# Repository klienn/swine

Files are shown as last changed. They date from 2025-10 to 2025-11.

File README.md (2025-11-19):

# SwineTrack – Right on Time, Healthy Swine

SwineTrack is an end-to-end sensing platform for pig pens. A primary ESP32 collects BME680 air-quality data, MLX90640 thermal grids, and pulls RGB frames from an ESP32-CAM. The firmware pushes signed telemetry to Supabase Functions/Storage, exposes a local real-time thermal stream, and drives the same datasets that power the mobile application APIs documented below.

---

## Table of Contents
- [Overview](#overview)
- [Repository Layout](#repository-layout)
- [Hardware Reference](#hardware-reference)
- [Firmware Setup](#firmware-setup)
  - [swine-esp32 (sensor + uploader)](#swine-esp32-sensor--uploader)
  - [swine-esp32-cam (optical module)](#swine-esp32-cam-optical-module)
- [Local Thermal Endpoints](#local-thermal-endpoints)
- [Cloud Pipeline & APIs](#cloud-pipeline--apis)
  - [Edge Upload Endpoints](#edge-upload-endpoints)
    - [GET /config](#get-config)
    - [POST /ingest-live-thermal](#post-ingest-live-thermal)
    - [POST /ingest-live-frame](#post-ingest-live-frame)
    - [POST /ingest-snapshot](#post-ingest-snapshot)
  - [Client/App Data Access](#clientapp-data-access)
    - [1. Live](#1-live)
    - [2. Snapshots (Diary)](#2-snapshots-diary)
    - [3. Readings (History)](#3-readings-history)
    - [4. Alerts](#4-alerts)
- [License](#license)

---

## Overview

The updated deployment uses **two ESP32-class boards on the same Wi-Fi**:

- `swine-esp32` (DevKitC/WROVER class) owns the sensors, hosts a local SSE thermal stream, and uploads multi-part payloads to Supabase Functions using an HMAC signature (`X-Device-Id`, `X-Timestamp`, `X-Signature`).
- `swine-esp32-cam` (AI Thinker-style ESP32-CAM) stays close to the animals and exposes `http://<cam>/capture?...` for RGB frames. The main board polls this endpoint so the heavier neural/video work can happen in the cloud.

On the cloud side the data lands in Storage buckets (`frames-live`, `snapshots`) and Postgres tables (`readings`, `alerts`). The React Native sample code from the old README still applies, so it lives in the **Client/App Data Access** section.

---

## Repository Layout

- `swine-esp32/` – main firmware (`swine-esp32.ino`) plus helpers:
  - `swinetrack_sensors.h` – BME680 + MLX90640 setup, VOC heuristics, JSON builders.
  - `async_http_uploader.h` – background TLS uploader with retry/backpressure.
  - `swinetrack_http.h` – Wi-Fi/time helpers, camera fetch, remote config, TLS CA (`swt_certs.h`).
  - `swinetrack_local_server.h` – lightweight HTTP/SSE server for thermal previews.
  - `esp32_bb.png` / `esp32.fzz` – wiring reference for the sensor shield.
- `swine-esp32-cam/` – ESP32-CAM sketch based on Espressif’s WebServer example (`board_config.h`, `app_httpd.cpp`).
- `README.md` – this document.

---

## Hardware Reference

Minimum bill of materials:

- ESP32 DevKitC / WROVER module with PSRAM (main board).
- ESP32-CAM (AI-Thinker profile by default).
- MLX90640 thermal array (I²C @ 0x33).
- BME680 environmental sensor (I²C @ 0x76/0x77).
- Shared 5 V supply for camera and 3.3 V for the sensors.

`swine-esp32/esp32_bb.png` and `swine-esp32/esp32.fzz` show the exact wiring. Core signals:

| Peripheral | ESP32 Pin | Notes |
|---|---|---|
| I²C SDA | GPIO21 | Shared between BME680 + MLX90640 |
| I²C SCL | GPIO22 | 100 kHz at boot, bumped to 400 kHz after init |
| Camera | Wi-Fi | `CAMERA_URL` must resolve from the main ESP32 |

Keep the two boards on the same SSID. The `swine-esp32` firmware will reboot itself if Wi-Fi or SNTP cannot be re-established.

---

## Firmware Setup

### swine-esp32 (sensor + uploader)

1. **Install libraries**: ESP32 board support ≥ 3.x, `Adafruit BME680`, `Adafruit MLX90640`, `ArduinoJson`, plus the default ESP32 Wi-Fi stack (already bundled).
2. **Edit configuration constants** in `swine-esp32/swine-esp32.ino`:
   - `WIFI_SSID` / `WIFI_PASS` – WPA2 credentials.
   - `FN_BASE` – Supabase Functions base URL (`https://<ref>.functions.supabase.co`).
   - `DEVICE_ID` / `DEVICE_SECRET` – provisioned per device; the secret signs every HTTPS request.
   - `CAMERA_URL` – default `http://cam-pen1.local/capture?res=VGA` but overridden remotely via `/config`.
   - `LIVE_FRAME_INTERVAL_MS`, `READING_INTERVAL_MS`, `REALTIME_THERMAL_INTERVAL_MS`, `FEVER_C`, etc. (all tunable via `/config`).
3. **Verify certificates** inside `swine-esp32/swt_certs.h`. Replace the pin if Supabase rotates their CA chain.
4. **Build & flash** with an “ESP32 Dev Module” (or WROVER) profile and a partition scheme that offers ≥3 MB for the app plus PSRAM.

Behavior highlights:

- Wi-Fi guard + SNTP sync keep the device online; if cloud sync fails it still publishes to the local SSE server.
- The thermal server (port `8787`) publishes events every `REALTIME_THERMAL_INTERVAL_MS` (~50 ms) and survives even when Supabase is unreachable.
- Remote configuration: once time sync succeeds, the device hits `GET /config` for `camera_url`, `live_frame_interval_s`, `reading_interval_s`, `overlay_alpha`, and `fever_c`. Failures just fall back to the compiled defaults.
- `AsyncUploader` batches multi-part POSTs on core 1. It drops stale live frames (>10 s) and prioritizes alerts via `enqueuePriority`.
- Snapshots trigger when `MLX90640` reports `tMax > FEVER_C` or the BME680 gas resistance drops more than `kAirQualityRatioThreshold` (1.5×) from baseline. A five-minute cooldown prevents alert spam.

### swine-esp32-cam (optical module)

- Uses Espressif’s camera HTTP server with the AI-Thinker pinout (`board_config.h`). Enable a different board by uncommenting the relevant macro.
- Configure Wi-Fi credentials in `swine-esp32-cam/swine-esp32-cam.ino` (`ssid`, `password`). Use the same network as the main board to allow zeroconf hostnames like `cam-pen1.local`.
- After flashing, the camera exposes:
  - `http://<cam-ip>/capture` (what the main board hits, optionally with `?res=VGA` / `SVGA`),
  - `http://<cam-ip>/stream` (for debugging from a browser),
  - the default control UI at the root path.
- Keep PSRAM enabled for dual frame buffers; otherwise the firmware auto-drops to SVGA.

---

## Local Thermal Endpoints

`swine-esp32` exposes a helper server on `http://<device-ip>:8787` (hostname defaults to `esp32main.local`). Endpoints:

- `/status` – `{"status":"ok","path":"/thermal/latest","stream":"/thermal-stream"}` for health checks.
- `/thermal/latest` – last JSON payload that was published, shaped as:
  ```json
  {
    "capturedAt": 1714078123456,
    "tMin": 28.42,
    "tMax": 39.73,
    "tAvg": 32.11,
    "thermal": {
      "w": 32,
      "h": 24,
      "data": [... 768 floats ...],
      "tMin": 28.42,
      "tMax": 39.73,
      "tAvg": 32.11
    }
  }
  ```
- `/thermal-stream` – Server-Sent Events (`event: thermal`) pushing the same payload once the MLX90640 reader publishes it.

Example:
```
curl http://esp32main.local:8787/thermal/latest | jq .
curl http://esp32main.local:8787/thermal-stream
```

These endpoints run regardless of cloud connectivity so you can debug aiming/focus in the field.

---

## Cloud Pipeline & APIs

### Edge Upload Endpoints

All HTTPS calls go to `${FN_BASE}` over TLS 1.2 with CA pinning (`SUPABASE_ROOT_CA`). Every request includes:

- `X-Device-Id` – matches `DEVICE_ID`.
- `X-Timestamp` – `nowMs()` (Unix epoch in milliseconds).
- `X-Signature` – `HMAC_SHA256(deviceSecret, "<METHOD>\n<path>\n<bodyHash>\n<timestamp>")`.

`bodyHash` is `sha256Hex` of the raw multipart body. Multipart parts (when present) follow these names:

| Part name | Content type | Description |
|---|---|---|
| `cam` | `image/jpeg` | Binary frame pulled from the ESP32-CAM. |
| `thermal` | `application/json`| Output of `makeThermalJson` (32×24 grid, min/max/avg). |
| `reading` | `application/json`| BME680 scalars + thermal summary (`makeReadingJson` / alert context). |

#### GET /config

- **Purpose** – allow remote tuning without reflashing.
- **Response** – example:
  ```json
  {
    "camera_url": "http://cam-pen1.local/capture?res=VGA",
    "config": {
      "live_frame_interval_s": 1,
      "reading_interval_s": 180,
      "overlay_alpha": 0.35,
      "fever_c": 39.5
    }
  }
  ```
- The firmware retries every 120 s until `gConfigFetched` becomes true.

#### POST /ingest-live-thermal

- Pushed every `LIVE_FRAME_INTERVAL_MS` as long as the cloud is reachable.
- Contains **thermal** and **reading** JSON parts, no camera JPEG (saves bandwidth when the RGB fetch fails).
- Server should respond within 60 s so the uploader’s queue does not back up.

#### POST /ingest-live-frame

- Sent right after the thermal packet if pulling the camera JPEG succeeded.
- Includes all three parts (`cam`, `thermal`, `reading`). Frames are skipped when the queue has ≤1 free slot to keep the stream fresh.
- Ideal place to update the `frames-live/<device_id>/current.jpg` object used by the app.

#### POST /ingest-snapshot

- Triggered on gas anomalies or fever spikes (`FEVER_C`). Uses `enqueuePriority` so the uploader clears any stale work first.
- Carries the same multipart payload as live frames but should create a `snapshots` record + overlay asset + `alerts` entry.
- Device enforces a 5-minute cooldown (`SNAPSHOT_COOLDOWN_MS`) before sending another alert.

### Client/App Data Access

Mobile/web clients read data straight from Supabase buckets + Postgres. The helpers below are unchanged from the earlier README and still apply to the refreshed pipeline.

#### 1. Live
Each device continuously overwrites:
```
frames-live/<device_id>/current.jpg (or .png)
```

##### API + Hook
```ts
// src/features/live/api.ts
import { supabase } from '@/lib/supabase';

export async function getLiveFrameUrl(deviceId: string, ttlSec = 10) {
  const jpg = await supabase.storage.from('frames-live').createSignedUrl(`${deviceId}/current.jpg`, ttlSec);
  if (jpg.data?.signedUrl) return `${jpg.data.signedUrl}&cb=${Date.now()}`;
  const png = await supabase.storage.from('frames-live').createSignedUrl(`${deviceId}/current.png`, ttlSec);
  if (png.data?.signedUrl) return `${png.data.signedUrl}&cb=${Date.now()}`;
  throw new Error('no_live_frame');
}
```

```ts
// src/features/live/useLiveFrame.ts
import { useEffect, useState } from 'react';
import { getLiveFrameUrl } from './api';

export function useLiveFrame(deviceId: string, intervalMs = 1000) {
  const [url, setUrl] = useState<string|null>(null);
  const [err, setErr] = useState<string|null>(null);

  useEffect(() => {
    let alive = true, timer: any;
    const tick = async () => {
      try { setUrl(await getLiveFrameUrl(deviceId, 10)); setErr(null); }
      catch (e:any) { setErr(String(e?.message ?? e)); }
      finally { if (alive) timer = setTimeout(tick, intervalMs); }
    };
    tick();
    return () => { alive = false; clearTimeout(timer); };
  }, [deviceId, intervalMs]);

  return { url, err };
}
```

##### Screen Example
```tsx
// src/screens/LiveScreen.tsx
import React from 'react';
import { View, Image, ActivityIndicator, Text } from 'react-native';
import { useDevice } from '@/context/DeviceContext';
import { useLiveFrame } from '@/features/live/useLiveFrame';

export default function LiveScreen() {
  const { deviceId } = useDevice();
  const { url, err } = useLiveFrame(deviceId!, 1000); // 1 fps polling

  if (!deviceId) return <Text>Select a device</Text>;
  if (!url) return <ActivityIndicator />;

  return (
    <View style={{ padding: 12 }}>
      <Image source={{ uri: url }} style={{ width: '100%', aspectRatio: 4/3 }} />
      {err ? <Text style={{ color: 'orange', marginTop: 8 }}>warning: {err}</Text> : null}
    </View>
  );
}
```

#### 2. Snapshots (Diary)
Database table:
```
snapshots(device_id, ts, overlay_path, reading_id, alert_id)
```

##### API
```ts
// src/features/snapshots/api.ts
import { supabase } from '@/lib/supabase';

export type SnapshotRow = {
  id: number; device_id: string; ts: string;
  overlay_path: string; reading_id: number|null;
  reading?: {
    ts: string; temp_c: number|null; humidity_rh: number|null;
    pressure_hpa: number|null; gas_res_ohm: number|null; iaq: number|null;
    t_min_c: number|null; t_max_c: number|null; t_avg_c: number|null;
  } | null;
};

export async function listSnapshots(deviceId: string, page=0, pageSize=20) {
  const { data, error } = await supabase
    .from('snapshots')
    .select(`
      id, device_id, ts, overlay_path, reading_id,
      reading:readings ( ts, temp_c, humidity_rh, pressure_hpa, gas_res_ohm, iaq, t_min_c, t_max_c, t_avg_c )
    `)
    .eq('device_id', deviceId)
    .order('ts', { ascending: false })
    .range(page*pageSize, page*pageSize + pageSize - 1);

  if (error) throw error;

  return Promise.all((data ?? []).map(async (row:any) => {
    const { data: s } = await supabase.storage
      .from('snapshots')
      .createSignedUrl(row.overlay_path, 60*30);
    return { ...row, imageUrl: s?.signedUrl ?? null };
  }));
}
```

#### 3. Readings (History)
Query last 7 days by default.

##### API
```ts
// src/features/readings/api.ts
import { supabase } from '@/lib/supabase';

export type ReadingRow = {
  id:number; device_id:string; ts:string;
  temp_c:number|null; humidity_rh:number|null; pressure_hpa:number|null;
  gas_res_ohm:number|null; iaq:number|null; t_min_c:number|null; t_max_c:number|null; t_avg_c:number|null;
};

export async function fetchReadings(deviceId: string, fromISO: string, toISO: string, limit=1000) {
  const { data, error } = await supabase
    .from('readings')
    .select('id, device_id, ts, temp_c, humidity_rh, pressure_hpa, gas_res_ohm, iaq, t_min_c, t_max_c, t_avg_c')
    .eq('device_id', deviceId)
    .gte('ts', fromISO)
    .lte('ts', toISO)
    .order('ts', { ascending: false })
    .limit(limit);
  if (error) throw error;
  return data as ReadingRow[];
}
```

#### 4. Alerts
Table schema:
```
alerts(device_id, ts, kind, severity, message, reading_id)
```

##### API
```ts
// src/features/alerts/api.ts
import { supabase } from '@/lib/supabase';

export async function listAlerts(deviceId: string, page=0, pageSize=50) {
  const { data, error } = await supabase
    .from('alerts')
    .select('*')
    .eq('device_id', deviceId)
    .order('ts', { ascending: false })
    .range(page*pageSize, page*pageSize + pageSize - 1);
  if (error) throw error;
  return data;
}
```

---

## License
MIT © 2025 SwineTrack Team

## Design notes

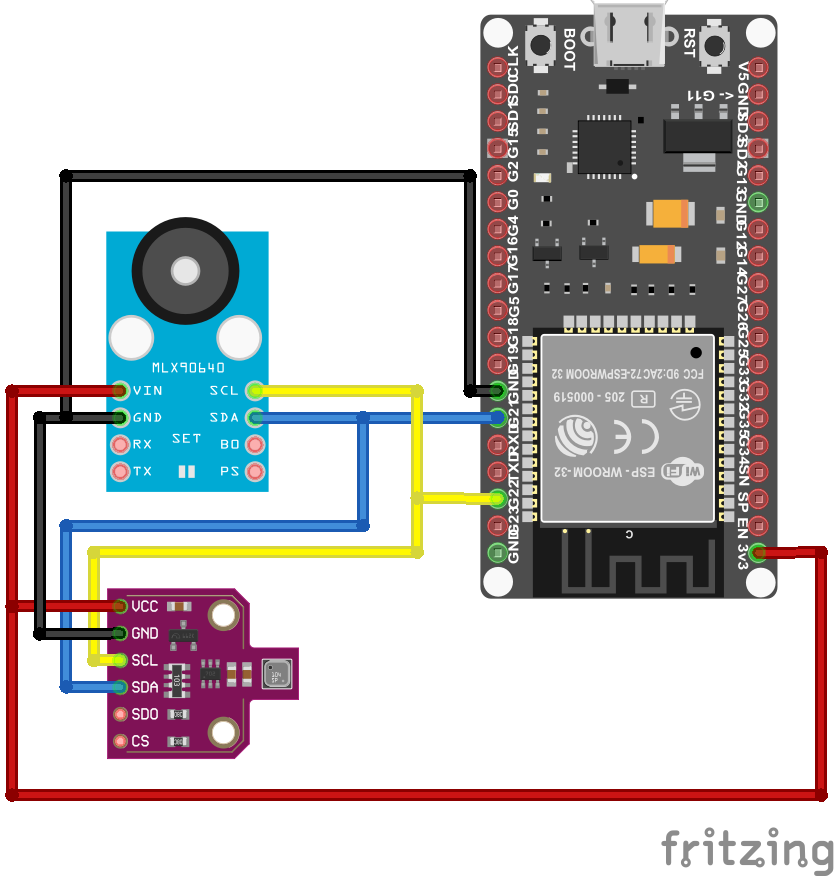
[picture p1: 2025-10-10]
swine-esp32/esp32_bb.png

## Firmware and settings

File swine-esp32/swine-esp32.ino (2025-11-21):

#include "swinetrack_http.h"
#include "swinetrack_sensors.h"
#include "async_http_uploader.h"
#include "swinetrack_local_server.h"

using namespace swt;

const char* WIFI_SSID = "MERCUSYS_0D8A";
const char* WIFI_PASS = "22854186";
const char* FN_BASE = "https://tqhbmujdtqxqivaesydq.functions.supabase.co";
const char* DEVICE_ID = "798d7d0b-965c-4eff-ba65-ce081bc139eb";
const char* DEVICE_SECRET = "05d35d61907b85a1422636bc2518eea0e3e0e72342e32a2cba02505a313ed379";
const char* LIVE_CAMERA_ENDPOINT = "/ingest-live-frame";
const char* LIVE_THERMAL_ENDPOINT = "/ingest-live-thermal";

String CAMERA_URL = "http://cam-pen1.local/capture?res=VGA";
uint32_t LIVE_FRAME_INTERVAL_MS = 1000;
uint32_t READING_INTERVAL_MS = 180000;
const uint32_t SNAPSHOT_COOLDOWN_MS = 5UL * 60UL * 1000UL;
uint32_t REALTIME_THERMAL_INTERVAL_MS = 50;
float OVERLAY_ALPHA = 0.35;
float FEVER_C = 39.5;
const uint16_t THERMAL_STREAM_PORT = 8787;

struct ThermalViewState {
  bool valid;
  float tMin;
  float tMax;
  float tAvg;
  uint64_t capturedAtMs;
};

static ThermalViewState gLatestThermalView = {false, 0.0f, 0.0f, 0.0f, 0};

static inline void recordLatestThermalView(float tMin, float tMax, float tAvg,
                                          uint64_t capturedAtMs) {
  gLatestThermalView.valid = true;
  gLatestThermalView.tMin = tMin;
  gLatestThermalView.tMax = tMax;
  gLatestThermalView.tAvg = tAvg;
  gLatestThermalView.capturedAtMs = capturedAtMs;
}

Adafruit_BME680 bme;
Adafruit_MLX90640 mlx;
float mlxFrame[32 * 24];
float gasBaseline = 0;

uint32_t lastLive = 0, lastReading = 0, lastRealtimeThermal = 0;
bool gCloudOnline = false;
bool gConfigFetched = false;
uint32_t gLastTimeSyncAttemptMs = 0;
uint32_t gLastConfigAttemptMs = 0;
const uint32_t CLOUD_SYNC_RETRY_MS = 60000;
const uint32_t CONFIG_FETCH_RETRY_MS = 120000;

// One background uploader for all endpoints
AsyncUploader uploader(FN_BASE, DEVICE_ID, DEVICE_SECRET);

void setup() {
  Serial.begin(115200);
  delay(150);

  WiFi.mode(WIFI_STA);
  WiFi.setSleep(false);
  WiFi.persistent(false);
  WiFi.setAutoReconnect(true);
  WiFi.setHostname("esp32main");

  ensureWifiOrReboot(WIFI_SSID, WIFI_PASS, 20000);
  gLastTimeSyncAttemptMs = millis();
  gCloudOnline = syncTime(20000);
  if (!gCloudOnline) {
    Serial.println("[setup] time sync failed; running in local-only mode");
  }

  initI2CBus(21, 22, 100000);
  initBME680(bme);
  initMLX90640(mlx);
  setI2CClock(400000);

  if (gCloudOnline) {
    Serial.println("[setup] fetching remote config...");
    gLastConfigAttemptMs = millis();
    gConfigFetched = fetchConfig(FN_BASE, DEVICE_ID, DEVICE_SECRET,
                                 CAMERA_URL, LIVE_FRAME_INTERVAL_MS, READING_INTERVAL_MS,
                                 OVERLAY_ALPHA, FEVER_C);
    if (!gConfigFetched) {
      Serial.println("[setup] config fetch failed; keeping defaults");
    }
  } else {
    Serial.println("[setup] skipping remote config fetch (offline)");
  }

  Serial.printf("FN_BASE: '%s'\n", FN_BASE);
  Serial.printf("Config: live=%lums read=%lums alpha=%.2f fever=%.1f cam=%s\n",
                LIVE_FRAME_INTERVAL_MS, READING_INTERVAL_MS, OVERLAY_ALPHA, FEVER_C,
                CAMERA_URL.c_str());

  uploader.begin(24576);
  swt::startRealtimeThermalServer(THERMAL_STREAM_PORT);
}

void loop() {
  const uint32_t now = millis();
  swt::serviceRealtimeThermalServer();

  if (now - lastRealtimeThermal >= REALTIME_THERMAL_INTERVAL_MS) {
    float rtMin = 0, rtMax = 0, rtAvg = 0;
    readMLX90640(mlx, mlxFrame);
    String realtimeJson = makeThermalJson(mlxFrame, rtMin, rtMax, rtAvg);
    const uint64_t realtimeCapturedAt = swt::nowMs();
    swt::publishRealtimeThermal(realtimeJson, rtMin, rtMax, rtAvg, realtimeCapturedAt);
    recordLatestThermalView(rtMin, rtMax, rtAvg, realtimeCapturedAt);
    lastRealtimeThermal = now;
  }

  // Wi-Fi guard
  static uint32_t lastGuard = 0;
  if (now - lastGuard >= 10000) {
    ensureWifiOrReboot(WIFI_SSID, WIFI_PASS, 10000);
    if (WiFi.status() == WL_CONNECTED) {
      if (!gCloudOnline && (now - gLastTimeSyncAttemptMs) >= CLOUD_SYNC_RETRY_MS) {
        Serial.println("[net] retrying time sync...");
        gLastTimeSyncAttemptMs = now;
        gCloudOnline = syncTime(5000);
        if (gCloudOnline) {
          Serial.println("[net] time sync restored; enabling cloud features");
          gConfigFetched = false;  // force config refresh
        }
      }
      if (gCloudOnline && !gConfigFetched &&
          (now - gLastConfigAttemptMs) >= CONFIG_FETCH_RETRY_MS) {
        Serial.println("[net] fetching remote config...");
        gLastConfigAttemptMs = now;
        gConfigFetched = fetchConfig(FN_BASE, DEVICE_ID, DEVICE_SECRET,
                                     CAMERA_URL, LIVE_FRAME_INTERVAL_MS, READING_INTERVAL_MS,
                                     OVERLAY_ALPHA, FEVER_C);
        if (!gConfigFetched) {
          Serial.println("[net] config fetch failed; will retry");
        }
      }
    }
    lastGuard = now;
  }
  if (WiFi.status() != WL_CONNECTED) {
    delay(50);
    return;
  }

  // Cached scalars / thermal summary
  static float lastTemp = 0, lastHum = 0, lastPress = 0, lastGas = 0, lastIAQ = 0;
  static float tMin = 0, tMax = 0, tAvg = 0;

  // Periodic sensor read
  if (now - lastReading >= READING_INTERVAL_MS) {
    if (readBME680(bme, lastTemp, lastHum, lastPress, lastGas)) {
      lastIAQ = 0;
      readMLX90640(mlx, mlxFrame);
      String _tmp = makeThermalSummaryJson(mlxFrame, tMin, tMax, tAvg);  // just to refresh stats
      _tmp = String();
      lastReading = now;
    }
  }

  // Camera fetch backoff
  static uint8_t camFailCount = 0;
  static uint32_t camBackoffUntil = 0;

  // --- near-live frame push (summary thermal; full grid NOT needed) ---
  if (now - lastLive >= LIVE_FRAME_INTERVAL_MS) {
    float liveTMin = 0, liveTMax = 0, liveTAvg = 0;
    readMLX90640(mlx, mlxFrame);
    String thJson = makeThermalJson(mlxFrame, liveTMin, liveTMax, liveTAvg);
    const uint64_t liveCapturedAt = swt::nowMs();
    swt::publishRealtimeThermal(thJson, liveTMin, liveTMax, liveTAvg, liveCapturedAt);
    recordLatestThermalView(liveTMin, liveTMax, liveTAvg, liveCapturedAt);
    lastRealtimeThermal = now;
    if (gCloudOnline) {
      String rdJson = makeReadingJson(lastTemp, lastHum, lastPress, lastGas, lastIAQ,
                                      liveTMin, liveTMax, liveTAvg);

      if (uploader.enqueue(LIVE_THERMAL_ENDPOINT, std::vector<uint8_t>(), thJson, rdJson)) {
        Serial.printf("[loop] thermal sample enqueued @ %lu ms\n", (unsigned long)now);
      } else {
        Serial.println("[loop] thermal sample DROPPED (queue backpressure)");
      }

      const bool cameraAllowed = (camBackoffUntil == 0) || (now >= camBackoffUntil);
      if (cameraAllowed) {
        std::vector<uint8_t> jpeg;
        uint32_t tFetch0 = millis();
        bool camOk = swt::fetchCamera(CAMERA_URL, jpeg);
        uint32_t fetchMs = millis() - tFetch0;

        if (camOk) {
          Serial.printf("[loop] camera fetch ok in %lums, size=%u (heap=%u)\n",
                        (unsigned long)fetchMs, (unsigned)jpeg.size(), ESP.getFreeHeap());
          camFailCount = 0;
          camBackoffUntil = 0;

          if (uploader.enqueue(LIVE_CAMERA_ENDPOINT, std::move(jpeg), thJson, rdJson)) {
            Serial.printf("[loop] live frame enqueued @ %lu ms\n", (unsigned long)now);
          } else {
            Serial.println("[loop] live frame DROPPED (queue backpressure)");
          }
        } else {
          Serial.printf("[loop] camera fetch FAILED after %lums\n", (unsigned long)fetchMs);
          camFailCount = min<uint8_t>(camFailCount + 1, 6);
          camBackoffUntil = now + (1000UL << camFailCount);
        }
      }

      rdJson = String();
    }

    thJson = String();
    lastLive = now;
  }

  // --- alert snapshot (full thermal grid), with cooldown ---
  static uint32_t alertCooldownUntil = 0;
  static uint32_t lastSnapshotAtMs = 0;
  static bool snapshotTimersInitialized = false;
  if (!snapshotTimersInitialized) {
    lastSnapshotAtMs = now;
    alertCooldownUntil = now;
    snapshotTimersInitialized = true;
  }
  const bool airQualityElevated = isAirQualityElevated(lastGas, gasBaseline);
  const float recentThermalMax = gLatestThermalView.valid ? gLatestThermalView.tMax : tMax;
  const bool feverAtTrigger = recentThermalMax > FEVER_C;
  const bool cooldownExpired = now >= alertCooldownUntil;
  const bool detectionTriggered = airQualityElevated || feverAtTrigger;
  const bool periodicDue = cooldownExpired && ((now - lastSnapshotAtMs) >= SNAPSHOT_COOLDOWN_MS);
  if (gCloudOnline && cooldownExpired && (detectionTriggered || periodicDue)) {
    std::vector<uint8_t> jpeg;
    if (swt::fetchCamera(CAMERA_URL, jpeg)) {
      readMLX90640(mlx, mlxFrame);
      float _tMin, _tMax, _tAvg;
      String thJson = makeThermalJson(mlxFrame, _tMin, _tMax, _tAvg);
      const uint64_t snapshotCapturedAt = swt::nowMs();
      swt::publishRealtimeThermal(thJson, _tMin, _tMax, _tAvg, snapshotCapturedAt);
      recordLatestThermalView(_tMin, _tMax, _tAvg, snapshotCapturedAt);
      lastRealtimeThermal = now;
      const bool feverNow = _tMax > FEVER_C;
      const bool feverObserved = feverAtTrigger || feverNow;
      const bool triggeredByPeriodicOnly = periodicDue && !detectionTriggered;
      const char* triggerReason = triggeredByPeriodicOnly
                                    ? "periodic"
                                  : airQualityElevated && feverObserved
                                      ? "air+fever"
                                    : airQualityElevated ? "air"
                                    : feverObserved      ? "fever"
                                                         : "unknown";
      String rdJson = makeAlertContextJson(lastTemp, lastHum, lastPress, lastGas, lastIAQ,
                                           _tMin, _tMax, _tAvg, recentThermalMax, gasBaseline, FEVER_C,
                                           airQualityElevated, feverNow, feverAtTrigger,
                                           triggerReason, lastReading, snapshotCapturedAt, now);
      if (uploader.enqueuePriority("/ingest-snapshot", std::move(jpeg), thJson, rdJson)) {
        Serial.printf("[loop] snapshot queued (alert priority, reason=%s, gas=%.2f baseline=%.2f, prevMax=%.2f thresh=%.1f, newMax=%.2f)\n",
                      triggerReason, lastGas, gasBaseline, recentThermalMax, FEVER_C, _tMax);
        alertCooldownUntil = now + SNAPSHOT_COOLDOWN_MS;
        lastSnapshotAtMs = now;
      } else {
        Serial.printf("[loop] snapshot enqueue FAILED (alert priority, reason=%s, gas=%.2f baseline=%.2f, prevMax=%.2f thresh=%.1f, newMax=%.2f)\n",
                      triggerReason, lastGas, gasBaseline, recentThermalMax, FEVER_C, _tMax);
      }
      thJson = String();
      rdJson = String();
    }
  }

  delay(3);
}

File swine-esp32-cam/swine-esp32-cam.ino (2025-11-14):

#include "esp_camera.h"
#include <WiFi.h>

// ===========================
// Select camera model in board_config.h
// ===========================
#include "board_config.h"

// ===========================
// Enter your WiFi credentials
// ===========================
const char *ssid = "MERCUSYS_0D8A";
const char *password = "22854186";

void startCameraServer();
void setupLedFlash();

void setup() {
  Serial.begin(115200);
  Serial.setDebugOutput(true);
  Serial.println();

  camera_config_t config;
  config.ledc_channel = LEDC_CHANNEL_0;
  config.ledc_timer = LEDC_TIMER_0;
  config.pin_d0 = Y2_GPIO_NUM;
  config.pin_d1 = Y3_GPIO_NUM;
  config.pin_d2 = Y4_GPIO_NUM;
  config.pin_d3 = Y5_GPIO_NUM;
  config.pin_d4 = Y6_GPIO_NUM;
  config.pin_d5 = Y7_GPIO_NUM;
  config.pin_d6 = Y8_GPIO_NUM;
  config.pin_d7 = Y9_GPIO_NUM;
  config.pin_xclk = XCLK_GPIO_NUM;
  config.pin_pclk = PCLK_GPIO_NUM;
  config.pin_vsync = VSYNC_GPIO_NUM;
  config.pin_href = HREF_GPIO_NUM;
  config.pin_sccb_sda = SIOD_GPIO_NUM;
  config.pin_sccb_scl = SIOC_GPIO_NUM;
  config.pin_pwdn = PWDN_GPIO_NUM;
  config.pin_reset = RESET_GPIO_NUM;
  config.xclk_freq_hz = 20000000;
  config.frame_size = FRAMESIZE_UXGA;
  config.pixel_format = PIXFORMAT_JPEG;  // for streaming
  //config.pixel_format = PIXFORMAT_RGB565; // for face detection/recognition
  config.grab_mode = CAMERA_GRAB_WHEN_EMPTY;
  config.fb_location = CAMERA_FB_IN_PSRAM;
  config.jpeg_quality = 12;
  config.fb_count = 1;

  // if PSRAM IC present, init with UXGA resolution and higher JPEG quality
  //                      for larger pre-allocated frame buffer.
  if (config.pixel_format == PIXFORMAT_JPEG) {
    if (psramFound()) {
      config.jpeg_quality = 10;
      config.fb_count = 2;
      config.grab_mode = CAMERA_GRAB_LATEST;
    } else {
      // Limit the frame size when PSRAM is not available
      config.frame_size = FRAMESIZE_SVGA;
      config.fb_location = CAMERA_FB_IN_DRAM;
    }
  } else {
    // Best option for face detection/recognition
    config.frame_size = FRAMESIZE_240X240;
#if CONFIG_IDF_TARGET_ESP32S3
    config.fb_count = 2;
#endif
  }

#if defined(CAMERA_MODEL_ESP_EYE)
  pinMode(13, INPUT_PULLUP);
  pinMode(14, INPUT_PULLUP);
#endif

  // camera init
  esp_err_t err = esp_camera_init(&config);
  if (err != ESP_OK) {
    Serial.printf("Camera init failed with error 0x%x", err);
    return;
  }

  sensor_t *s = esp_camera_sensor_get();
  // initial sensors are flipped vertically and colors are a bit saturated
  if (s->id.PID == OV3660_PID) {
    s->set_vflip(s, 1);        // flip it back
    s->set_brightness(s, 1);   // up the brightness just a bit
    s->set_saturation(s, -2);  // lower the saturation
  }
  // drop down frame size for higher initial frame rate
  if (config.pixel_format == PIXFORMAT_JPEG) {
    s->set_framesize(s, FRAMESIZE_QVGA);
  }

#if defined(CAMERA_MODEL_M5STACK_WIDE) || defined(CAMERA_MODEL_M5STACK_ESP32CAM)
  s->set_vflip(s, 1);
  s->set_hmirror(s, 1);
#endif

#if defined(CAMERA_MODEL_ESP32S3_EYE)
  s->set_vflip(s, 1);
#endif

// Setup LED FLash if LED pin is defined in camera_pins.h
#if defined(LED_GPIO_NUM)
  setupLedFlash();
#endif

  WiFi.begin(ssid, password);
  WiFi.setSleep(false);

  Serial.print("WiFi connecting");
  while (WiFi.status() != WL_CONNECTED) {
    delay(500);
    Serial.print(".");
  }
  Serial.println("");
  Serial.println("WiFi connected");

  startCameraServer();

  Serial.print("Camera Ready! Use 'http://");
  Serial.print(WiFi.localIP());
  Serial.println("' to connect");
}

void loop() {
  // Do nothing. Everything is done in another task by the web server
  delay(10000);
}

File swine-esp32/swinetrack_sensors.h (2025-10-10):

#pragma once
#include <Wire.h>
#include <Adafruit_BME680.h>
#include <Adafruit_MLX90640.h>

namespace swt {

constexpr float kAirQualityRatioThreshold = 1.5f;

inline void initI2CBus(int sda, int scl, uint32_t khz100 = 100000) {
  Wire.begin(sda, scl);
  Wire.setClock(khz100);
  Wire.setTimeOut(50);
  delay(50);
}

inline void setI2CClock(uint32_t hz) {
  Wire.setClock(hz);
}

inline bool initBME680(Adafruit_BME680& bme) {
  uint8_t addrUsed = 0;
  bool ok = bme.begin(0x76, &Wire);
  if (ok) addrUsed = 0x76;
  if (!ok) {
    ok = bme.begin(0x77, &Wire);
    if (ok) addrUsed = 0x77;
  }

  if (!ok) {
    Serial.println("BME680 not found @ 0x76/0x77");
    return false;
  }

  Serial.printf("BME680 OK @ 0x%02X\n", addrUsed);
  bme.setTemperatureOversampling(BME680_OS_8X);
  bme.setHumidityOversampling(BME680_OS_2X);
  bme.setPressureOversampling(BME680_OS_4X);
  bme.setGasHeater(320, 150);
  return true;
}

inline bool initMLX90640(Adafruit_MLX90640& mlx) {
  if (!mlx.begin(0x33, &Wire)) {
    Serial.println("MLX90640 not found @ 0x33");
    return false;
  }
  mlx.setMode(MLX90640_CHESS);
  mlx.setResolution(MLX90640_ADC_18BIT);
  mlx.setRefreshRate(MLX90640_2_HZ);
  return true;
}

inline bool readBME680(Adafruit_BME680& bme, float& tempC, float& hum, float& pressHpa, float& gasRes) {
  if (!bme.performReading()) return false;
  tempC = bme.temperature;
  hum = bme.humidity;
  pressHpa = bme.pressure / 100.0f;
  gasRes = bme.gas_resistance;
  return true;
}

inline bool readMLX90640(Adafruit_MLX90640& mlx, float* outFrame) {
  mlx.getFrame(outFrame);  // 32x24 floats
  return true;
}

inline String makeThermalJson(const float* frame, float& tMin, float& tMax, float& tAvg) {
  tMin = 1e9;
  tMax = -1e9;
  double sum = 0;
  for (int i = 0; i < 32 * 24; i++) {
    float v = frame[i];
    if (v < tMin) tMin = v;
    if (v > tMax) tMax = v;
    sum += v;
  }
  tAvg = sum / (32.0 * 24.0);

  String json;
  json.reserve(6000);
  json = "{\"w\":32,\"h\":24,\"data\":[";
  for (int i = 0; i < 32 * 24; i++) {
    json += String(frame[i], 2);
    if (i < 32 * 24 - 1) json += ",";
  }
  // add tMin, tMax, tAvg to JSON
  json += "],\"tMin\":" + String(tMin, 2)
       + ",\"tMax\":" + String(tMax, 2)
       + ",\"tAvg\":" + String(tAvg, 2)
       + "}";
  return json;
}

inline String makeThermalSummaryJson(const float* frame, float& tMin, float& tMax, float& tAvg) {
  tMin = 1e9;
  tMax = -1e9;
  double sum = 0;
  for (int i = 0; i < 32 * 24; i++) {
    float v = frame[i];
    if (v < tMin) tMin = v;
    if (v > tMax) tMax = v;
    sum += v;
  }
  tAvg = sum / (32.0 * 24.0);
  String s = "{\"w\":32,\"h\":24"
             ",\"tMin\":"
             + String(tMin, 2) + ",\"tMax\":" + String(tMax, 2) + ",\"tAvg\":" + String(tAvg, 2) + "}";
  return s;
}

inline String makeReadingJson(float tempC, float hum, float press, float gasRes, float iaq,
                              float tMin, float tMax, float tAvg) {
  String s = "{\"tempC\":" + String(tempC, 1)
             + ",\"humidity\":" + String(hum, 1)
             + ",\"pressure\":" + String(press, 1)
             + ",\"gasRes\":" + String(gasRes, 0)
             + ",\"iaq\":" + String(iaq, 1)
             + ",\"tMin\":" + String(tMin, 2)
             + ",\"tMax\":" + String(tMax, 2)
             + ",\"tAvg\":" + String(tAvg, 2)
             + "}";
  return s;
}

// simple VOC proxy via gasRes drop vs baseline

inline bool isAirQualityElevated(float gasRes, float& baseline) {
  if (baseline <= 0) baseline = gasRes;
  float ratio = baseline > 0 ? (baseline / gasRes) : 1.0f;
  return ratio > kAirQualityRatioThreshold;
}

inline void appendUint64(String& out, uint64_t value) {
  if (value == 0) {
    out += '0';
    return;
  }
  char buf[21];
  int i = 0;
  while (value > 0 && i < (int)sizeof(buf)) {
    buf[i++] = char('0' + (value % 10));
    value /= 10;
  }
  while (i > 0) {
    out += buf[--i];
  }
}

inline String makeAlertContextJson(float tempC, float hum, float press, float gasRes, float iaq,
                                   float snapTMin, float snapTMax, float snapTAvg, float prevTMax,
                                   float gasBaseline, float feverThresholdC,
                                   bool airQualityElevated, bool feverDetectedNow,
                                   bool feverDetectedAtTrigger, const char* triggerReason,
                                   uint32_t sensorSampleMs, uint64_t capturedAtMs,
                                   uint32_t uptimeMs) {
  const bool gasBaselineValid = gasBaseline > 0.0f;
  const float gasDelta = gasBaselineValid ? (gasBaseline - gasRes) : 0.0f;
  const float gasRatio = (gasBaselineValid && gasRes > 0.0f) ? (gasBaseline / gasRes) : 0.0f;
  const float feverDelta = snapTMax - feverThresholdC;
  const bool feverObserved = feverDetectedNow || feverDetectedAtTrigger;
  const bool hasSensorSample = sensorSampleMs > 0;
  const uint32_t sensorSampleAgeMs = hasSensorSample ? (uptimeMs - sensorSampleMs) : 0;
  uint64_t sensorSampleCapturedAtMs = 0;
  if (hasSensorSample && capturedAtMs >= sensorSampleAgeMs) {
    sensorSampleCapturedAtMs = capturedAtMs - (uint64_t)sensorSampleAgeMs;
  }
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

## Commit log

2025-09-09 arduino initial commit
2025-09-14 Shift streaming focus to hub ESP32
2025-10-10 added schematic diagram
    [esp32.fzz]
2025-11-14 fix no internet issue with local thermal serve
    [swine-esp32.ino]
2025-11-19 add caching to last thermal frame
